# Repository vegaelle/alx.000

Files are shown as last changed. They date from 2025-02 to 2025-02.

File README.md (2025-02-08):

# ALX.000

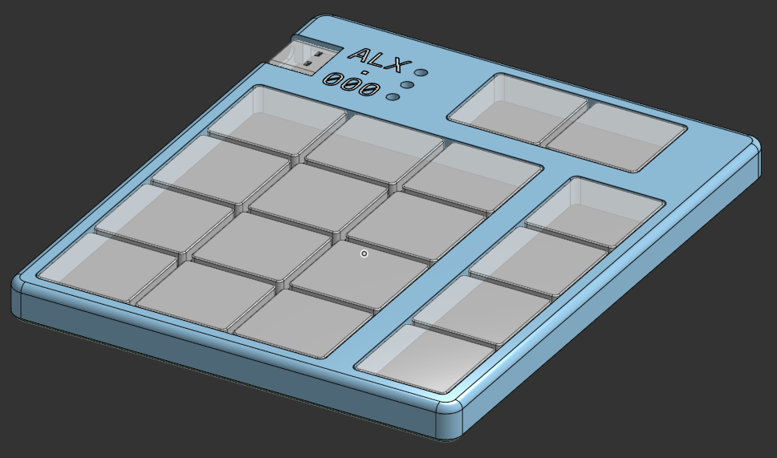
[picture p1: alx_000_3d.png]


ALX.000 is a compact 18-keys computer numpad, powered by a Seeed XIAO RP2040
micro-controller, and ultra-low-profile Kailh "X" PG1316S switches. It runs QMK,
although support for RMK may come later.

## What’s included here?

This repository contains all needed files for building the keyboard, including parts
list, assembly instructions and useful links.

- The [alx-000.json](alx-000.json) represents the keyboard shape,
produced by [Keyboard-Layout-Editor](https://www.keyboard-layout-editor.com/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,%0A%0A%0A%0A%0A%0A%0A%0A%2F%2F%3B&@=%0A%E2%86%90%0A%0A%0A%0A%0A%0A%0A%0A4&_t=%23000000&a:7&n:true%3B&=5&_t=%23000000%0A%23ff0000&a:4%3B&=%0A%E2%86%92%0A%0A%0A%0A%0A%0A%0A%0A6&_x:0.5%3B&=%0A%2F=%0A%0A%0A%0A%0A%0A%0A%0A*%3B&@=%0AEnd%0A%0A%0A%0A%0A%0A%0A%0A1&=%0A%E2%86%93%0A%0A%0A%0A%0A%0A%0A%0A2&=%0APgDn%0A%0A%0A%0A%0A%0A%0A%0A3&_x:0.5%3B&=%0A%3F%0A%0A%0A%0A%0A%0A%0A%0A-%3B&@=%0ABack%0A%0A%0A%0A%0A%0A%0A%0AEnt&=%0AIns%0A%0A%0A%0A%0A%0A%0A%0A0&=%0ADel%0A%0A%0A%0A%0A%0A%0A%0A.&_x:0.5%3B&=%0A%3F%0A%0A%0A%0A%0A%0A%0A%0A+)
- The [kicad](kicad/) directory contains the Kicad project, representing the PCB. It
uses [Scottokeebs](https://github.com/joe-scotto/scottokeebs/tree/main/Extras/ScottoKicad) libraries and [Mikefive](https://github.com/mikeholscher/zmk-config-mikefive/tree/main/files)’s footprints
- the PG1316 keycaps can be 3D-printed, either with the [blank model](pg1316s_keycap.3mf), or with the OpenSCAD script that allows customization, even with labels, in the [keycaps](keycaps) directory
- The case has been designed in [OnShape](https://cad.onshape.com/documents/826440f605c19707b80cd65a/w/c0d96e8d9f2b88321da9ff87/e/a88972e39d45dd27abd71d1e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). I would have liked to make it in FreeCAD but even in 1.0, it simply wasn’t usable enough.
- The [qmk_firmware/keyoards/alx/000](qmk_firmware/keyboards/alx/000) directory contains
the keyboard definition for QMK, required to build the firmware and edit the keymap.

## Why design a numpad in the first place?

1. Because it’s fun
2. I ultimately want to design my own ergomech keyboard, and this simple project is a
   first step
3. I wanted to try those ultra-thin switches, and it will be a nice way to try those

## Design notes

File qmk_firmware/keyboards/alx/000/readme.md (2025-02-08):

# alx/000

alx/000

*A short description of the keyboard/project*

* Keyboard Maintainer: [Gaëlle Robardet-Nicolas](https://github.com/vegaelle)
* Hardware Supported: *The PCBs, controllers supported*
* Hardware Availability: *Links to where you can find this hardware*

Make example for this keyboard (after setting up your build environment):

    make alx/000:default

Flashing example for this keyboard:

    make alx/000:default:flash

See the [build environment setup](https://docs.qmk.fm/#/getting_started_build_tools) and the [make instructions](https://docs.qmk.fm/#/getting_started_make_guide) for more information. Brand new to QMK? Start with our [Complete Newbs Guide](https://docs.qmk.fm/#/newbs).

## Bootloader

Enter the bootloader in 3 ways:

* **Bootmagic reset**: Hold down the key at (0,0) in the matrix (usually the top left key or Escape) and plug in the keyboard
* **Physical reset button**: Briefly press the button on the back of the PCB - some may have pads you must short instead
* **Keycode in layout**: Press the key mapped to `QK_BOOT` if it is available

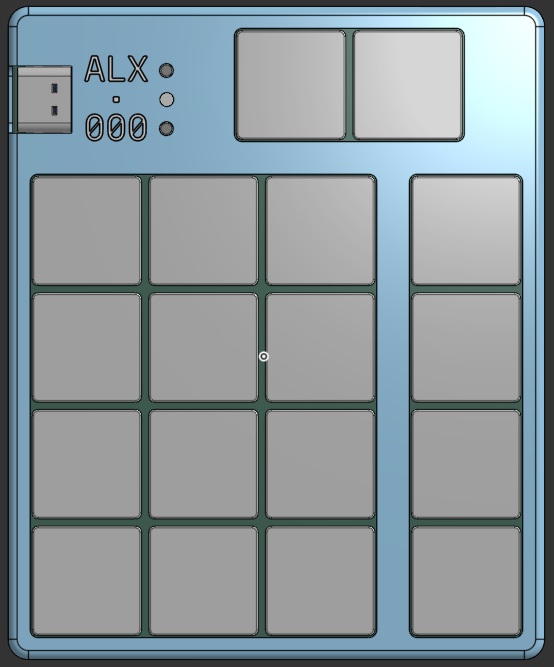
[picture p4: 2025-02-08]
alx_000_top.png

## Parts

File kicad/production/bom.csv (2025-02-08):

Designator | Footprint | Quantity | Value | LCSC Part #
D1, D10, D11, D12, D13, D14, D15, D16, D17, D18, D2, D3, D4, D5, D6, D7, D8, D9 | Diode_SOD-123 | 18 | D
SW1, SW10, SW11, SW12, SW13, SW14, SW15, SW16, SW17, SW18, SW2, SW3, SW4, SW5, SW6, SW7, SW8, SW9 | CPG1316S01D02_mikeholscher | 18 | Switch
U1 | Seeed_XIAO_RP2040 | 1 | MCU_Seeed_XIAO_RP2040

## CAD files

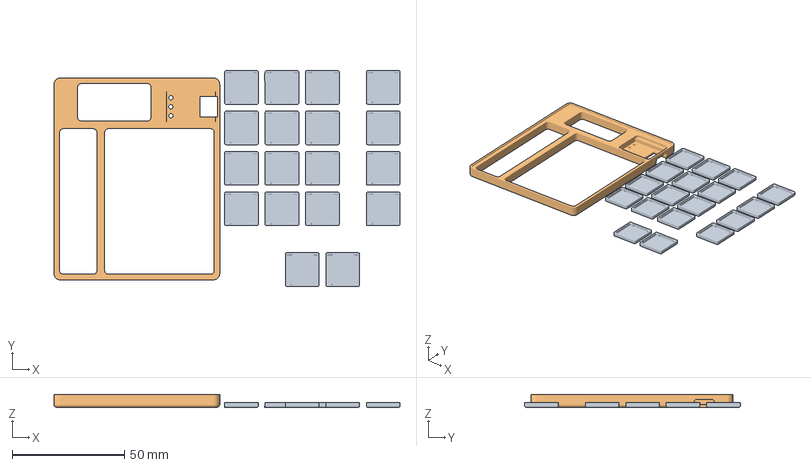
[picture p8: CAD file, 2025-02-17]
keycaps/alx-000-keycaps.3mf
153.9 x 96.0 x 5.63 mm
alx-000-keycaps
case

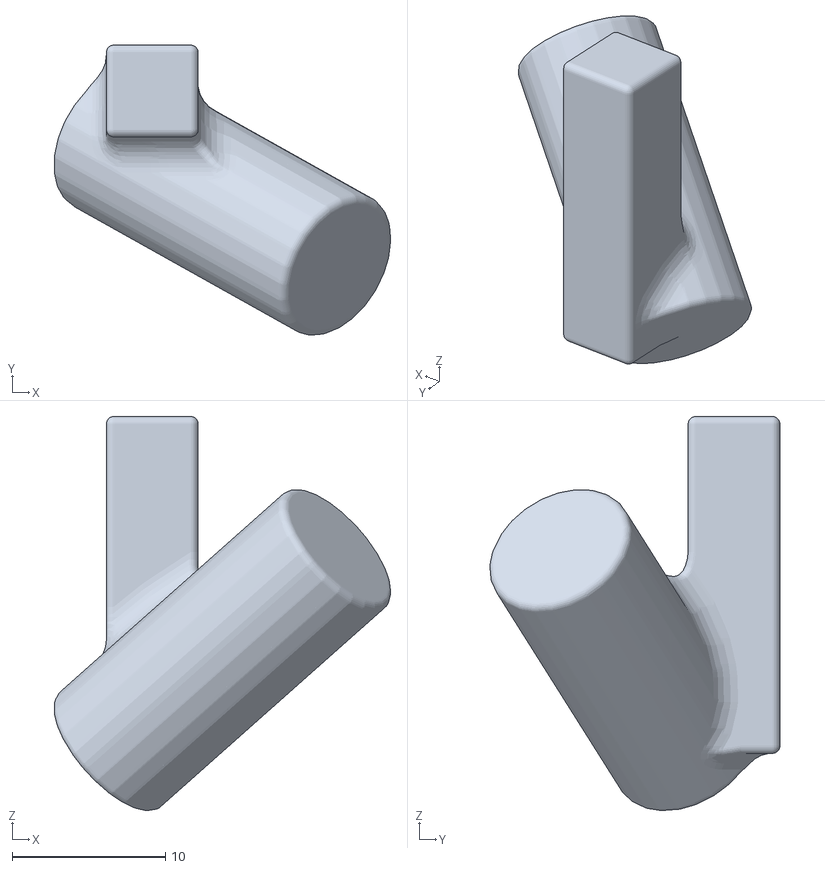
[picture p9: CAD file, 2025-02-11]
keycaps/scad_libs/Round-Anything-1.0.4/nicefillets.stl
22.0 x 18.9 x 25.7

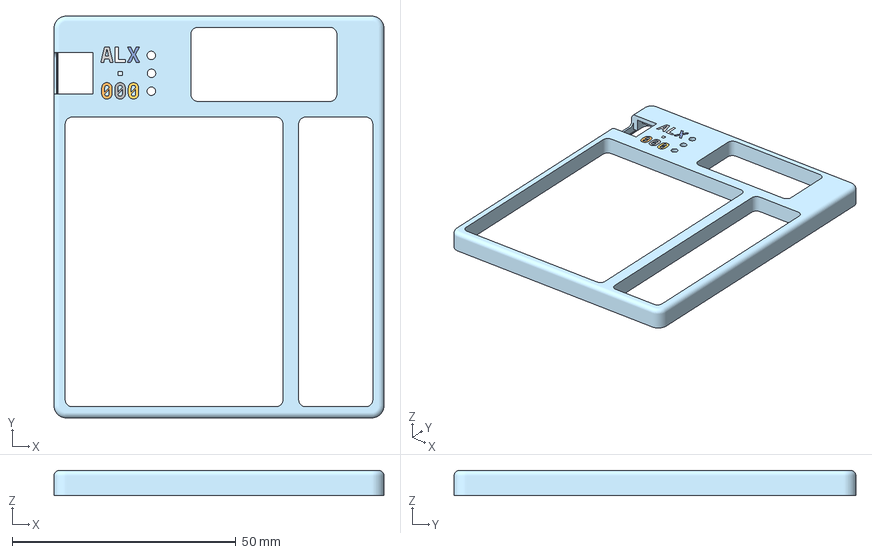
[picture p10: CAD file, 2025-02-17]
case.3mf
73.7 x 89.8 x 5.63 mm
Keyboard case

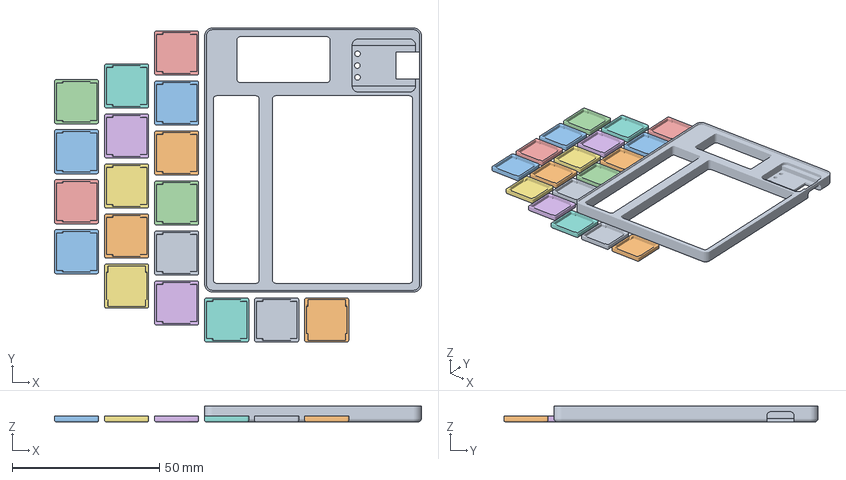
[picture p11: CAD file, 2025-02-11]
keycaps/keycap_0.3mf
124.7 x 106.8 x 5.43 mm
numpad_case
ptr_keycap
nav_keycap
0_keycap
6_keycap
1_keycap
7_keycap
4_keycap
star_keycap
plus_keycap
ret_keycap
8_keycap
9_keycap
2_keycap
3_keycap
minus_keycap
dot_keycap
slash_keycap
5_keycap

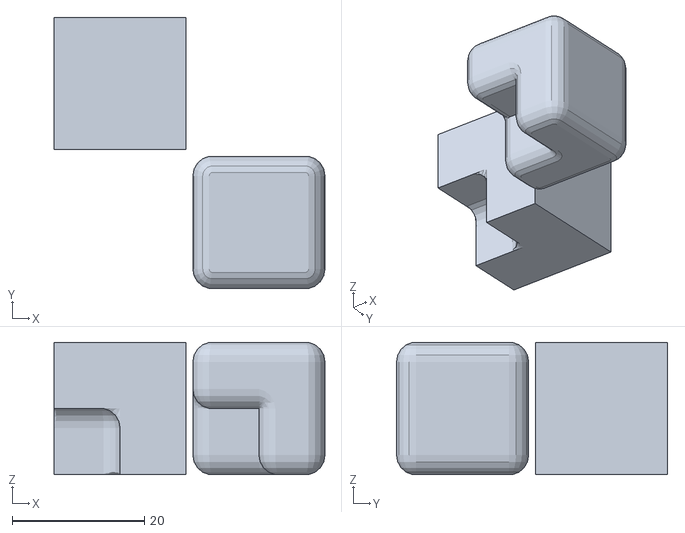
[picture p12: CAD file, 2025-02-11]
keycaps/scad_libs/Round-Anything-1.0.4/insideoutsiteround.stl
41.0 x 41.0 x 20.0

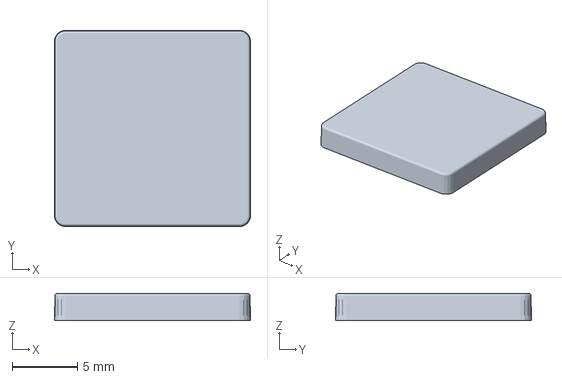
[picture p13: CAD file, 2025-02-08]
keycaps/pg1316s_keycap.3mf
15.1 x 15.1 x 2.10 mm

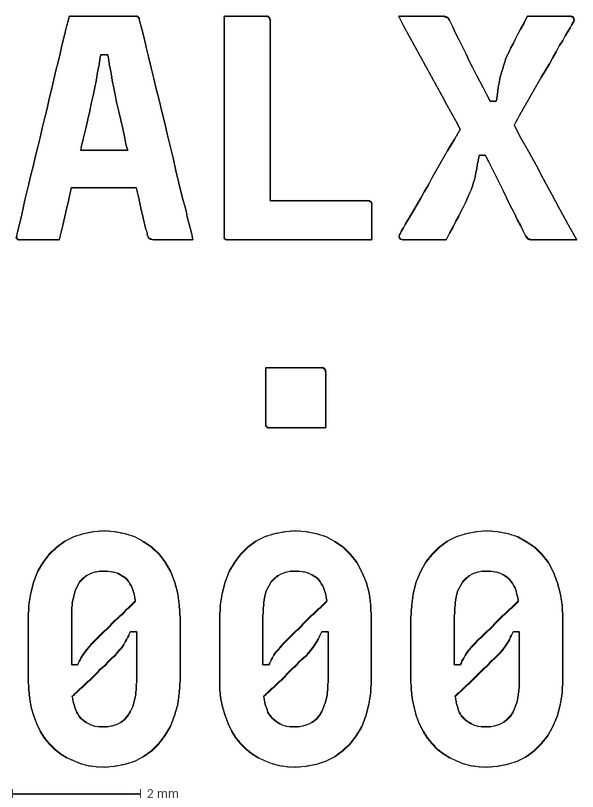
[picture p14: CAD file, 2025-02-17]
logo.dxf
8.69 x 11.6 mm

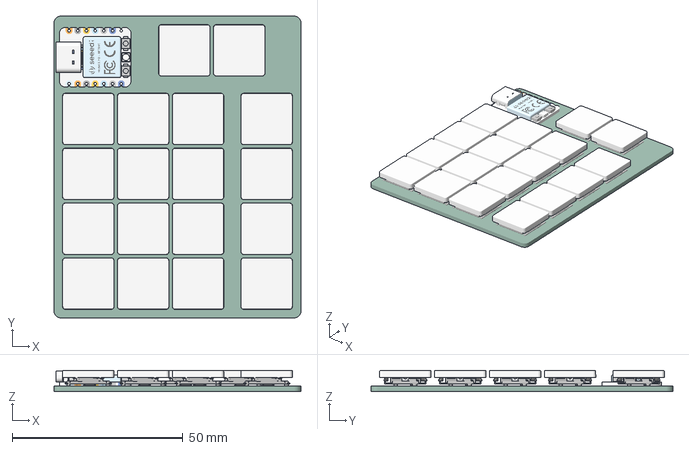
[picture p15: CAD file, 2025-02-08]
numpad_pcb.3mf
72.2 x 88.3 x 6.23 mm

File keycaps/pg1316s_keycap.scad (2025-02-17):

include <scad_libs/roundedcube.scad>

kc_inner_size = 13.8;
kc_outer_size = 15;
kc_shell_width = 0.6;
kc_height = 1.5;
kc_radius = 0.6;
kc_dx_supports = 9.18;
kc_dy_supports = 12.7;
kc_support_height = 1.5;
kc_support_inset_depth = 0.2;
kc_support_inset_height = 1.1;
kc_support_inset_width = 1.91;
kc_support_inset_bevel_height = 0.56;
kc_support_bevel_x_angle = 37;
kc_support_bevel_x_height = 0.69;
kc_support_bevel_y_angle = 45;
kc_support_bevel_y_height = 1.25;

kc_homing = false;
kc_homing_length = 4;
kc_homing_width = .6;
kc_homing_pos = .3;

// base positioning

kc_base_pos_x = 0;
kc_base_pos_y = 0;
kc_margin = 18;

// labels

kc_label_top_left = "";
kc_label_top_center = "";
kc_label_top_right = "";
kc_label_middle_left = "";
kc_label_middle_center = "";
kc_label_middle_right = "";
kc_label_bottom_left = "";
kc_label_bottom_center = "";
kc_label_bottom_right = "";

// labels settings

kc_label_font = "DejaVu Sans:style=Bold";
kc_center_label_relative_size = .35;
kc_label_relative_size = .22;
kc_label_positioning = .4;

// Parts to save. Must be "keycap", "labels" or "all"
kc_part = "keycap";

module support() {
    difference() {
        // Support base
        translate([kc_dx_supports/2,
                   kc_dy_supports/2,
                   kc_height - kc_support_height]) {
            difference() {
                difference() {
                    // support shape
                    cube(
                        [(kc_inner_size - kc_dx_supports)/2,
                         (kc_inner_size - kc_dy_supports)/2,
                         kc_support_height
                         ],
                         center=false
                    );
                    
                    // Support X bevel
                    translate([0, 0, kc_support_height - kc_support_bevel_x_height ]) {
                        rotate([0, 180, 0]) {
                            rotate([0, -kc_support_bevel_x_angle, 0]) {
                                cube(
                                    [kc_support_height - kc_support_bevel_x_height,
                                     (kc_inner_size - kc_dy_supports)/2,
                                     (kc_inner_size - kc_dx_supports)/2
                                     ]
                                );
                            }
                        }
                    }
                } // end X bevel

                // Support Y bevel
                translate([(kc_inner_size - kc_dx_supports)/2,
                           0,
                           kc_support_height - kc_support_bevel_y_height
                           ]) {
                    rotate([0, 180, 0]) {
                        rotate([kc_support_bevel_y_angle, 0, 0]) {
                            cube(
                                  [(kc_inner_size - kc_dx_supports)/2,
                                   kc_support_bevel_y_height,
                                   kc_support_bevel_y_height
                                   ]
                            );
                        }
                    }
                }
            } // end y bevel
        }
        // Support inset
        translate([kc_inner_size/2 - kc_support_inset_width,
                   kc_dy_supports/2,
                   kc_height - kc_support_inset_height]) {

            difference() {
                cube(
                    [kc_support_inset_width, kc_support_inset_depth, kc_support_inset_height],
                    center=false
                );    

                // Support bevel
                translate([0, 0, kc_support_inset_height - kc_support_inset_bevel_height ]) {
                    rotate([0, 180, 0]) {
                        rotate([0, -kc_support_bevel_x_angle, 0]) {
                            cube(
                                [kc_support_height - kc_support_bevel_x_height,
                                 (kc_inner_size - kc_dy_supports)/2,
                                 (kc_inner_size - kc_dx_supports)/2
                                 ]
                            );
                        }
                    }
                }

            }
        }
    }
}

module label(x, y, char) { 
        
    translate([x, y, kc_height]) {
        linear_extrude(height=kc_shell_width) {
            text(char,
                 font=kc_label_font,
                 halign="center",
                 valign="center",
                 size=kc_outer_size* (((x==0)&&(y==0)) ? kc_center_label_relative_size : kc_label_relative_size)
            );
        }
    }
}

translate([kc_base_pos_x * kc_margin, kc_base_pos_y * kc_margin, 0]) {  // position offset for each key
    rotate([180, 0, 0]) {  // face down
        if(kc_part != "labels") {
            difference() {

                union() {
                
                    color("gray") {

                        // Top layer
                        intersection() {
                            translate([0, 0, kc_height]) {
                                roundedcube(
                                    [kc_outer_size, kc_outer_size, kc_shell_width*2],
                                    center=true,
                                    radius=kc_radius
                                );
                            }
                            
                            translate([0, 0, kc_height + kc_shell_width/2]) {
                                cube(
                                    [kc_outer_size, kc_outer_size, kc_shell_width],
                                    center=true
                                );
                            }
                        }

                        // homing
                        if(kc_homing) {
                            translate([0, -(kc_outer_size*kc_homing_pos)/2, kc_height + kc_shell_width/2 + kc_homing_width/2]) {
                                roundedcube(
                                    [kc_homing_length, kc_homing_width, kc_homing_width],
                                    center=true,
                                    radius=kc_homing_width/2
                                );
                            }
                        }

                        // Sides
                        translate([0, 0, kc_height / 2]) {
                            difference() {
                                roundedcube(
                                    [kc_outer_size, kc_outer_size, kc_height],
                                    center=true,
                                    radius=kc_radius,
                                    apply_to="z"
                                );
                                roundedcube(
                                    [kc_inner_size, kc_inner_size, kc_height],
                                    center=true,
                                    radius=kc_radius,
                                    apply_to="z"
                                );
                            }
                        }
                        
                        support();
                        mirror([1, 0, 0]) {
                            support();
                        }
                        mirror([0, 1, 0]) {
                            support();
                        }
                        mirror([0, 1, 0]) {
                            mirror([1, 0, 0]) {
                                support();
                            }
                        }
                    }
                }

                // Labels pockets
                union() {
                    let(pos=(kc_outer_size - kc_outer_size * kc_label_positioning)/2) {
                        if(kc_label_top_left != undef) label(-pos, pos, kc_label_top_left);
                        if(kc_label_top_center != undef) label(0, pos, kc_label_top_center);
                        if(kc_label_top_right != undef) label(pos, pos, kc_label_top_right);
                        if(kc_label_middle_left != undef) label(-pos, 0, kc_label_middle_left);
                        if(kc_label_middle_center != undef) label(0, 0, kc_label_middle_center);
                        if(kc_label_middle_right != undef) label(pos, 0, kc_label_middle_right);
                        if(kc_label_bottom_left != undef)label(-pos, -pos, kc_label_bottom_left);
                        if(kc_label_bottom_center != undef) label(0, -pos, kc_label_bottom_center);
                        if(kc_label_bottom_right != undef) label(pos, -pos, kc_label_bottom_right);
                    }
                }
            }
        }
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

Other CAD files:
keycaps_and_case.3mf
keycaps/scad_libs/roundedcube.scad
keycaps/scad_libs/Round-Anything-1.0.4/MinkowskiRound.scad
keycaps/scad_libs/Round-Anything-1.0.4/polyround.scad
keycaps/scad_libs/Round-Anything-1.0.4/roundAnythingExamples.scad

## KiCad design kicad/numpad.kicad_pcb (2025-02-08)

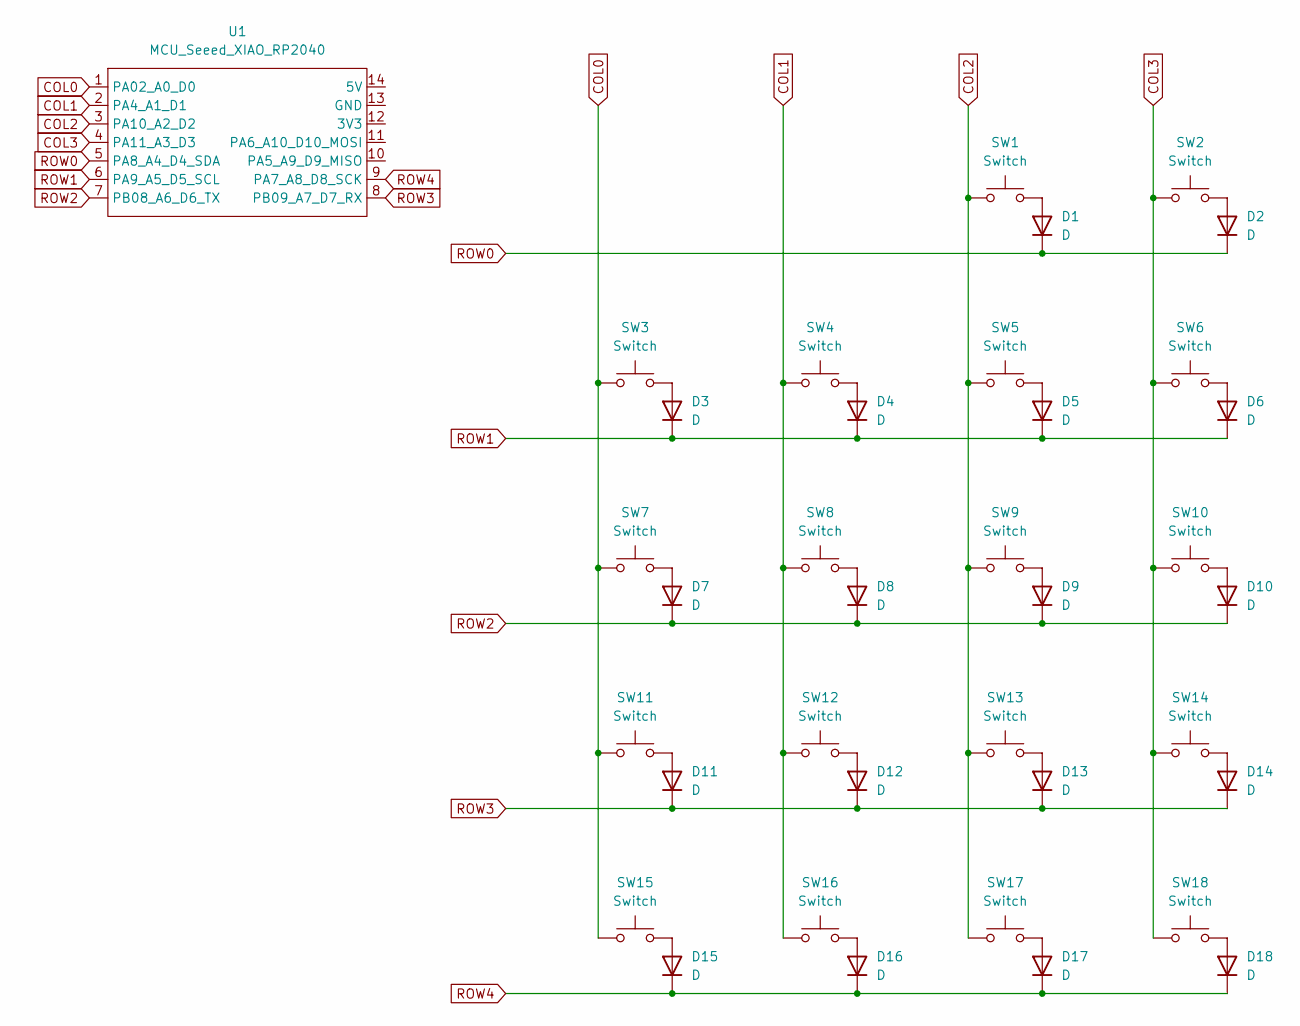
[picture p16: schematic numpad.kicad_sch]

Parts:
D1, D2, D3, D4, D5, D6, D7, D8, D9, D10, D11, D12, D13, D14, D15, D16, D17, D18: D; Diode_SOD-123
SW1, SW2, SW3, SW4, SW5, SW6, SW7, SW8, SW9, SW10, SW11, SW12, SW13, SW14, SW15, SW16, SW17, SW18: Switch; CPG1316S01D02_mikeholscher
U1: MCU_Seeed_XIAO_RP2040; Seeed_XIAO_RP2040

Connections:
COL0: SW3.1, SW7.1, SW11.1, SW15.1, U1.1 (PA02_A0_D0)
COL1: SW4.1, SW8.1, SW12.1, SW16.1, U1.2 (PA4_A1_D1)
COL2: SW1.1, SW5.1, SW9.1, SW13.1, SW17.1, U1.3 (PA10_A2_D2)
COL3: SW2.1, SW6.1, SW10.1, SW14.1, SW18.1, U1.4 (PA11_A3_D3)
unnamed: D1.2 (A), SW1.2
unnamed: D2.2 (A), SW2.2
unnamed: D3.2 (A), SW3.2
unnamed: D4.2 (A), SW4.2
unnamed: D5.2 (A), SW5.2
unnamed: D6.2 (A), SW6.2
unnamed: D7.2 (A), SW7.2
unnamed: D8.2 (A), SW8.2
unnamed: D9.2 (A), SW9.2
unnamed: D10.2 (A), SW10.2
unnamed: D11.2 (A), SW11.2
unnamed: D12.2 (A), SW12.2
unnamed: D13.2 (A), SW13.2
unnamed: D14.2 (A), SW14.2
unnamed: D15.2 (A), SW15.2
unnamed: D16.2 (A), SW16.2
unnamed: D17.2 (A), SW17.2
unnamed: D18.2 (A), SW18.2
ROW0: D1.1 (K), D2.1 (K), U1.5 (PA8_A4_D4_SDA)
ROW1: D3.1 (K), D4.1 (K), D5.1 (K), D6.1 (K), U1.6 (PA9_A5_D5_SCL)
ROW2: D7.1 (K), D8.1 (K), D9.1 (K), D10.1 (K), U1.7 (PB08_A6_D6_TX)
ROW3: D11.1 (K), D12.1 (K), D13.1 (K), D14.1 (K), U1.8 (PB09_A7_D7_RX)
ROW4: D15.1 (K), D16.1 (K), D17.1 (K), D18.1 (K), U1.9 (PA7_A8_D8_SCK)

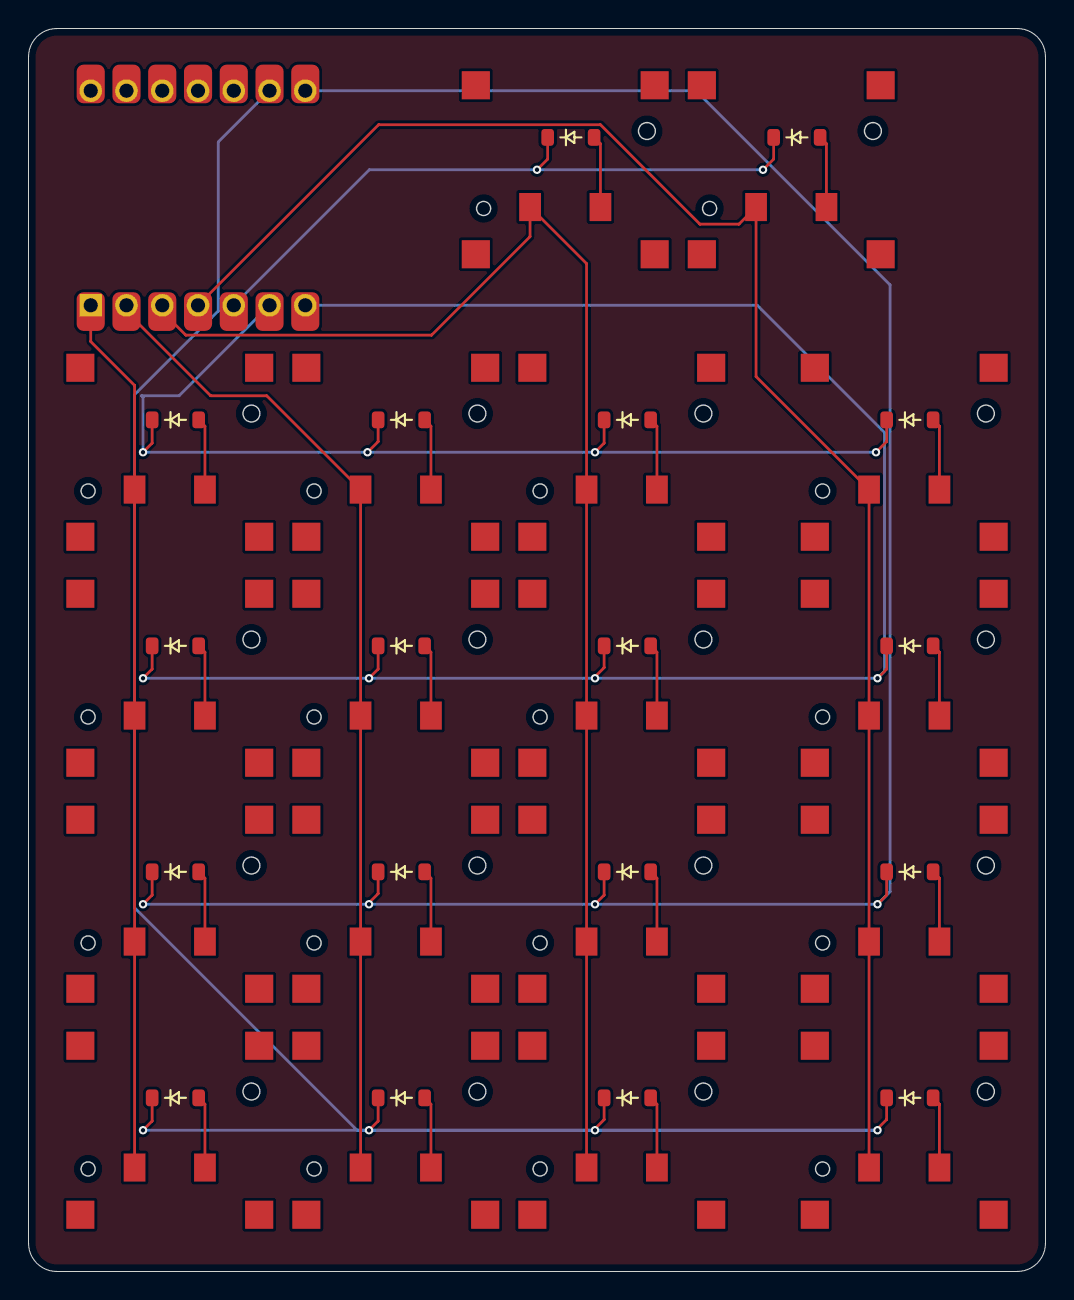
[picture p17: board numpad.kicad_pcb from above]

Board: 2 copper layers, 72.2 x 88.3 mm, 37 parts (0 on the bottom side), 27 nets.

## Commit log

2025-02-08 Add first version of numpad files
    [bom.csv, designators.csv, logo.dxf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]
2025-02-08 Try to use the RGB LED
2025-02-08 Fix RGB LED usage
2025-02-11 Add keycaps scad script and renders
    [0_keycap.stl, 0_labels.stl, 1_keycap.stl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]
2025-02-17 [WIP] Keycaps generation script, using lib3mf
    [0_keycap.stl, 0_labels.stl, 1_keycap.stl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]
2025-02-17 Add to_3mf working version of keycap generator script
    [alx-000-keycaps.3mf, case.3mf, keycaps_and_case.3mf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]
